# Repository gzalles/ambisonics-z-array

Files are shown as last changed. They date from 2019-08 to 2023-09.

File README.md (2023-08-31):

# MEMS Z-Array Mics

## [WIKI](https://github.com/gzalles/ambisonics-z-array/wiki)

A family of ambisonic microphones designed with MEMS capsules. These are affordable, easy-to-build arrays which can be used for multichannel audio recording (i.e., ambisonics).

Find an updated list of associated assets here:

1. m: Octave GNU code for plotting, analyzing and calibrating yourr own array
2. cad: various 3d objects you can print either online or at your university.
3. pcb: the files you need to make the pcbs or also you can have them made elsewhere.
4. svg: laser cutting files
5. conf: configuration files for kronlachner's convolution plug-in and filters
6. json: encoder presets for IEM MatrixMultiplier
7. wiki: instructions to build arrays

[AES Paper 1](https://www.researchgate.net/publication/320188555_A_Low-Cost_High-Quality_MEMS_Ambisonic_Microphone)

[AES Paper 2](https://www.researchgate.net/publication/338123588_Effects_of_Capsule_Coincidence_in_FOA_using_MEMS_Objective_Experiment)

<!-- TODO: move links to site.
 -->

## Pictures

<p align="center">
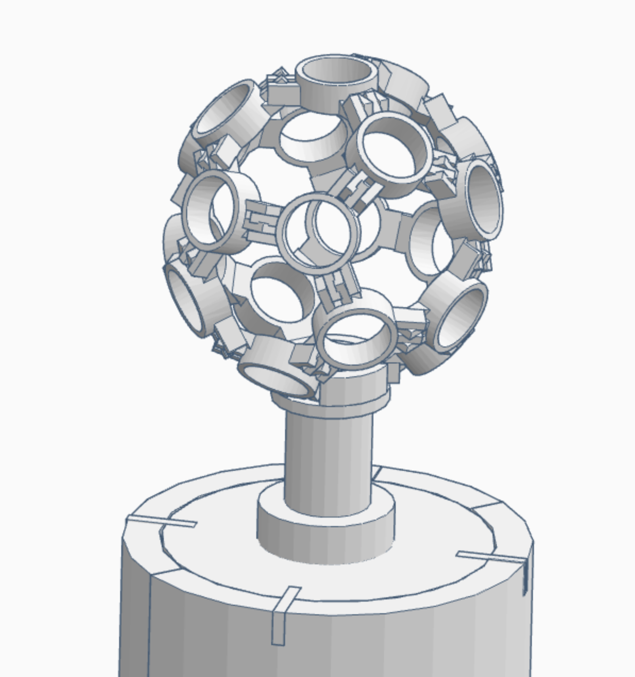
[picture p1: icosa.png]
  
  <figcaption>

BigSpHEAR by FLL (working on a permutation).

## Contributing

Feel free to fork and request merge if you are interested in the project. Email to gzalles at ucsd dot edu.

## Authors

* [**Gabriel Zalles Ballivian**](http://gabrielzalles.com/)

## License

This project is licensed under the MIT License - see the [LICENSE.md](LICENSE.md) file for details

## Acknowledgments

* Charles Middlicott
* Charlie Mydlarz
* Agnieszka Roginska
* Julian Vanesse
* Andrea Genovese
* Braxton Boren
* Fernando Lopez-Lezcano
* Julius O Smith
* Alex Tung (Qualcomm)
* Raimundi Gonzalez (MSMA)
* Spencer Capiello (NYU)

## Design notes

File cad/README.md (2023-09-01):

# CAD Files

Here are the STL files to build the various MC arrays. 

Key:
* MCH = name of the board
* ADA = adafruit 
* 16CH = 16 channel array
* 2D = two-dimensional (horizontal only)

* PDM = pulse density modulation (one of several protocols used)
* TDM = time domain multiplexing (same thing)
* I2S = Inter-IC Sound (same thing)
* IC = integrated circuit 

<!--
These are the CAD models we used for this design. At the moment these are not the best designs for low quality printers. We had to use a SLS printer (Form2) in order to get good results. We managed to get workable models on low-quality printers but after trial and error.

In the next design we are going to use the SpHear designs and modify them to make the MEMS fit. Hopefully that way these will be easier to print.

This file has 3 microphones since our experiment consisted of comparing these three designs.

The larger mic looks a little funny because the base is small relative to the head. This is because we wanted to keep the diameter of the cylinder the same and reduce print time. I was not sure my mic clip would work with larger diameter.

By the way, I use an alligator style mic clip [like this one](https://www.amazon.com/Audio-Universal-Microphone-Holder-Amc417x6/dp/B00P6VIPCS?ref_=fsclp_pl_dp_3) because the low quality prints can't handle the snap. Even if you use an SLS printer the neck is quite fragile so one of these bad boys would be good to have.

<p align="center">
  <img width="80%" height="80%" src="../img/threeSizes.JPG">
</p>
-->

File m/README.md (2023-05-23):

# Objective-C

I used ScanIR to get the impulse responses of my system. We also recycled the rotating mount project from our first paper to get polar measurements. This folder has functions and examples to calculate the DFR of the A-format signals and export the calibration filters.

I am eventually hoping to compare three methods of SMA encoding:

1. AF/BF calibration + static encoding matrix (using DFR for AF calibration and peak response for BF).
2. FM (filter matrix) encoding using ideal SHs to solve the system of linear equations.
3. Static encoding matrix plus radial filters. 

One could also combine these methods to try to find an optimal subjective solution. I am also conducting subjective evals via prolific.com

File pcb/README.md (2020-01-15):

# PCB Files

* 3_175mmRadius: panelized files (can also be found in zip format)
* mems_quart_board_ics_40720.brd : single PCB for editing if needed.

These are the panelized files for the ICS-40720 board that Charlie Mydlarz designed. The radius of the board is 3.175mm. These are the current boards we are using for the analog mems FOA mic. I also added the original without panelizing.

There is a lot of information of the datasheet online regarding these capsules. In order to acquire these board one must find a PCB manufacturer and pay them to send you the boards.

In our current design we opt for 1mm thickness.

We use 2-sided PCBs.

If you need the dimensions of the board you can use: http://www.gerber-viewer.com/

The only thing they ask is to upload the zipped file. I have added the zipped file for your convenience since all sites as for it this way.

You might also want to get a stencil. With it you can more easily apply the paste to you PCBs.

credit: charlie mydlarz.

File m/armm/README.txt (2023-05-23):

We should figure out how to build a robotic arm for IR measurements with low-cost printers and stuff. 

Fernando's arm is really expensive.

Part of this whole thing is automating the process as much as possible.

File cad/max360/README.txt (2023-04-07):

v1 max360 design (go pro camera attachment)

- use M3 screws, you need 2 per capsule (so 32) plus 2 more for the perf board and 2 more for the MCH board

- using the ICS41350 board by eighthree on github 

- mount should fit standard microphone mount 

- perf board is 22402A-18 

- MCHStreamer Kit board 

- top capsules are 20 degrees elevation.

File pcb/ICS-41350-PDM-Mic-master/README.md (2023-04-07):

# ICS-41350-PDM-Mic
Open Source pcb layout and design for InvenSense ICS-41350 PDM Mic

# Datasheet
https://www.invensense.com/wp-content/uploads/2016/02/DS-000047-ICS-41350-v1.1.pdf

# Order PCBs
https://oshpark.com/shared_projects/o22Ddhzi

# Order ICS-41350
https://www.digikey.ca/product-detail/en/tdk-invensense/ICS-41350/1428-1064-1-ND/6025660

You'll also need a 0805 10uF and a 0603 .1uF smd capacitors and a 0603 10K Resistor.

# Front and Back PCB Preview

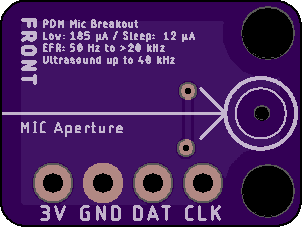
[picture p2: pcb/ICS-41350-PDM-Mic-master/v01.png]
Front PCB Design Front PCB, Aperture is highlighted by arrow

>The arrow points to where the hole for the mic goes.

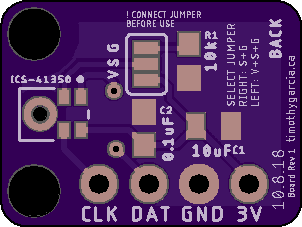
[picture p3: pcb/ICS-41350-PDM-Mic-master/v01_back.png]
Back PCB Design Back PCB, Jumper to select LEFT or RIGHT

>Bridge the S and G pad before using and bridge all three (S, G, V) if using module as RIGHT for stereo.

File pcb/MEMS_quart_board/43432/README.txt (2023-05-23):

43432 I2S Mic 

[VDD from J3 pin 2 on MCH]

LEFT and RIGHT PCBs (separate)

Left = CH1
Right = Ch2

Left tied to GRN (SEL)
Right tied to VDD (SEL)

MCH
///

BCLK > SCK 
LRCLK > WS 

Each data line has 2 channels. 
//////////////////////////////
J1 #2 input = channels 1/2
J1 #4 input = channels 3/4
etc.

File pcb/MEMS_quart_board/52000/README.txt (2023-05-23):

52000 TDM Mic

BCLK > SCK
FSYNC > WS

WS ---> WSO ---> WS ---> WSO 

Each data line has 8 channels. 
//////////////////////////////
J1 #2 input = channels 1-8
J1 #4 input = channels 9-16
etc.

[VDD from J3 pin 2 on MCH]

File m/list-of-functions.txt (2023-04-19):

working list of functions:
//////////////////////////

* load_spkr_resp - load speaker response (plot optional)
* load_AF - load A-format 
* load_single -load single capsule meas

* gen_refl_win - generate reflection window
* gen_spkr_eq - generate speaker EQ filter
* gen_helm_filt - generate helmholtz filter
* gen_AF_filt - generate A-format filters ("matching")
* gen_enc_mat - generate encoding matrix for array
* gen_BF_filt - generate B-format filters
* gen_reg_vec - generate regularization vector for N/K

* eq_AF - EQ A-format signals (for helm and/or A-format "matching" filter)
* eq_BF - EQ B-format signals

* export_AF_filt - export A-format filters in wav format
* export_BF_filt - export B-format filters in wav format
* export_enc_mat - export encoding matrix as csv

* plot_mag_one - plot a single IR (not polar) [magnitude]
* plot_mag_many - overlaying multiple IRs in a single figure [magnitude]
* plot_polar_single - plot polar for single capsule
* plot_polar_BF - plot polar B-format
* plot_polar_VM - plot polar virtual microphone 

! should we have plots for phase response?

* calc_dfr - calculate diffuse field response(s)
* calc_nk - calculate nelson/kirkeby (N/K) inverse filter
* calc_snr - calculate snr of signal 
* calc_toa - calculate time of arrival differences for all capsules. 

* norm_AF - normalize the AF signals based on global maxima
* norm_BF - normalize the BF signals based on W (loudest harmonic)

* conv_sweep2ir - convert sweep to ir
* conv_AF2BF_FOA - use a simple sum and difference matrix to convert AF to BF (FOA only).

ideas:
/////

1. should we make a function that precedes the DFR filter generation that adjusts the gain of the AF signals based on fulcrum offset? [gain_match_AF] this might be easy for FOA and octo but how about 16 channnel mic? is this the same as the AF filter using DFR? maybe it is... 

calc_toa:

We can use these to time-align the IRs. In other words, we can phase match the capsules. Important when array is not perfectly centered in ARMM. I think the way to do this is average all the FREQUENCY RESPONSES (not mag), then get the average phase response, then get the group delay, then match (Q-1) capsules. 

Another method might be to use the time domain iFFT averaged frequency response, and use some threshold to determine where the sweep starts. 

* mostly applicable to measurements, not so useful in real life. the capsules and CAD models are quite precise. 

* calculate SNR (create function)

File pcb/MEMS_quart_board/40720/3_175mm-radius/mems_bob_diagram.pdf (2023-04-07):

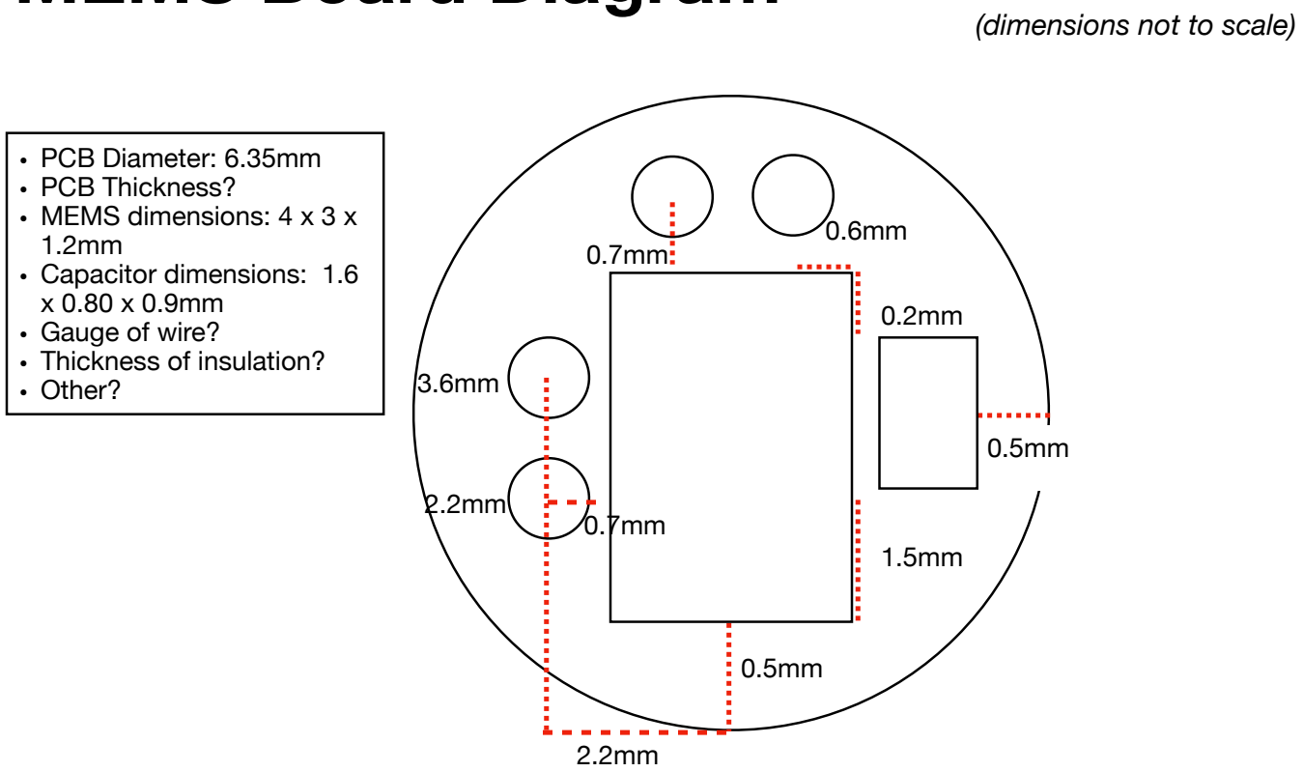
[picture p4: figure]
(dimensions not to scale); • PCB Diameter: 6.35mm • PCB Thickness? • MEMS dimensions: 4 x 3 x 1.2mm • Capacitor dimensions: 1.6 x 0.80 x 0.9mm • Gauge of wire? • Thickness of insulation? • Other?

http://www.gerber-viewer.com/ used gerber-viewer to measure (it takes a zipped file)

1.65mm between the two holes on top
1.4mm between the two holes on the side

# MEMS Board Diagram

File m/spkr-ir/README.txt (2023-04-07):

In order to confirm that REW does use the calib file you should compare the responses of both wav files!

/

Initial test of u-mik at home. I think I will try to do this again but do 4 or 8 repetitions. I have to put the dog in my room, he was moving around. 

The calib file incorporated the calibration file. I believe the export takes into account the calib file so long as it is correctly loaded, although I am not sure. I am still new to REW.

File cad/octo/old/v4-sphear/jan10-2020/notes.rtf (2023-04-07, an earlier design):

I used 50 percent infill on this print
I used the highest detail possible 0.18mm resolution.

I used MILANO at Envision and the PETG material (IC3D)
I did not use the glue stick.

The weird thing is the resolution setting for some of the other printers for high is 0.14mm. Maybe it has to do with the material?

——

I switched to the millennium falcon. It has PLA and .14mm resolution. The print looked like it was kind of failing on the other printer. It is not looking very good on this one but we’ll see. I will let is finish.

I also printed a few extra ones just in case some of them did not work.

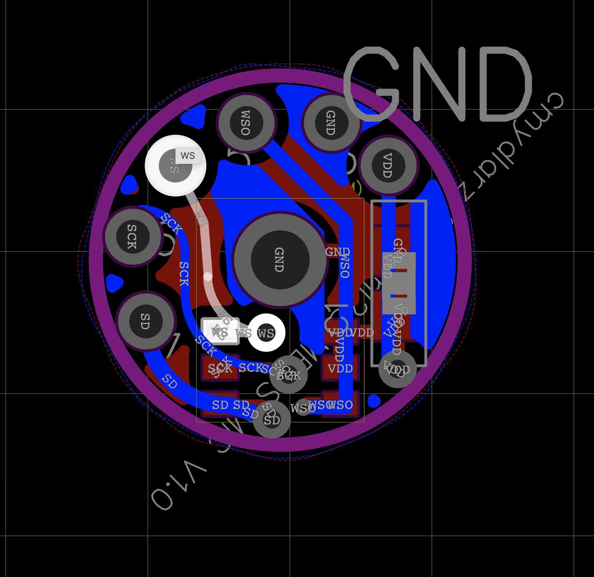
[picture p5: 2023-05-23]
pcb/MEMS_quart_board/52000/52000-pcb-pinout.png

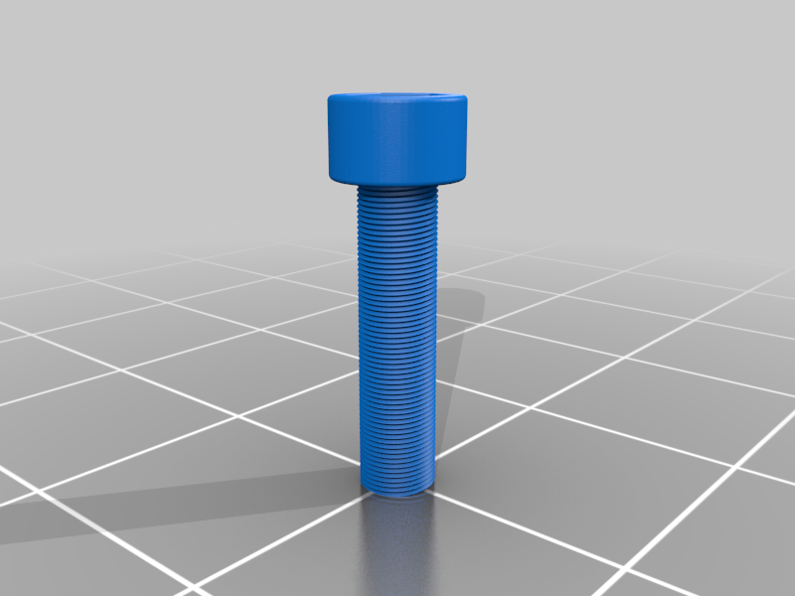
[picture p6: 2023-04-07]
cad/dl/screws/M3_SCREW_WITH_NUT_3730355/images/M3_HEX_SCREW.png

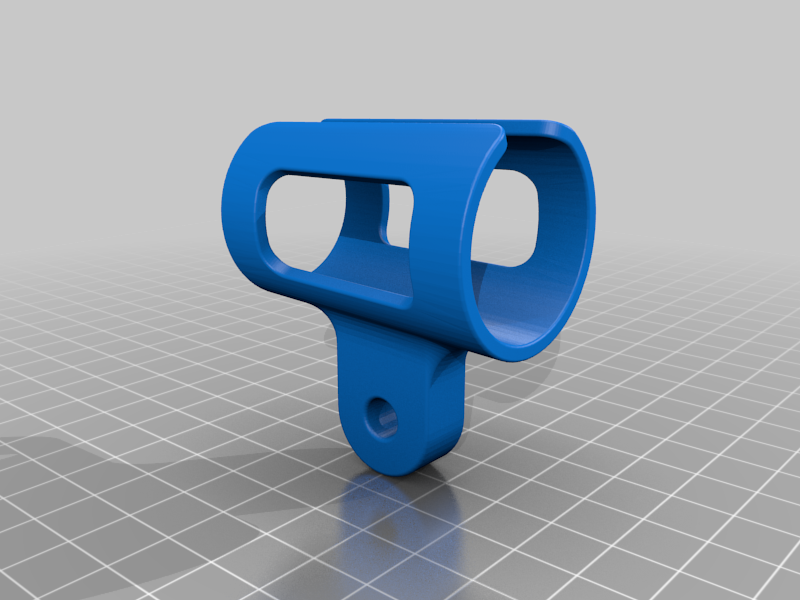
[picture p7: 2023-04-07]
cad/dl/mic-holder/images/Mic_Holder_Standard_Size.png

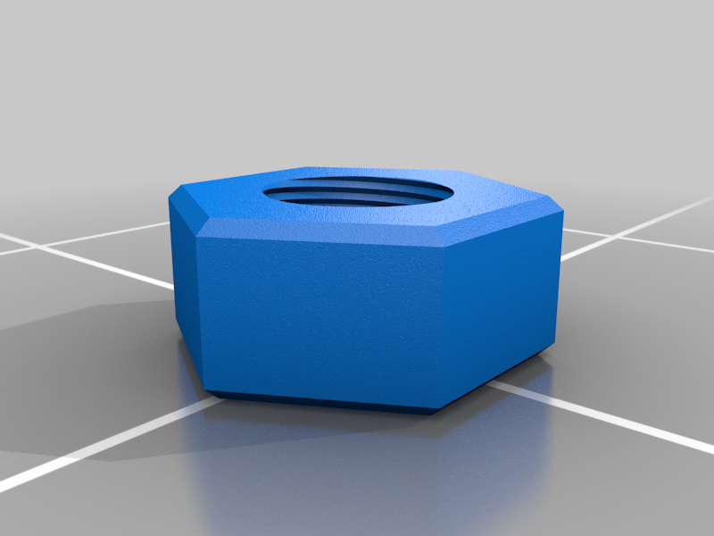
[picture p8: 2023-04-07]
cad/dl/screws/M3_SCREW_WITH_NUT_3730355/images/M3_HEX_NUT.png

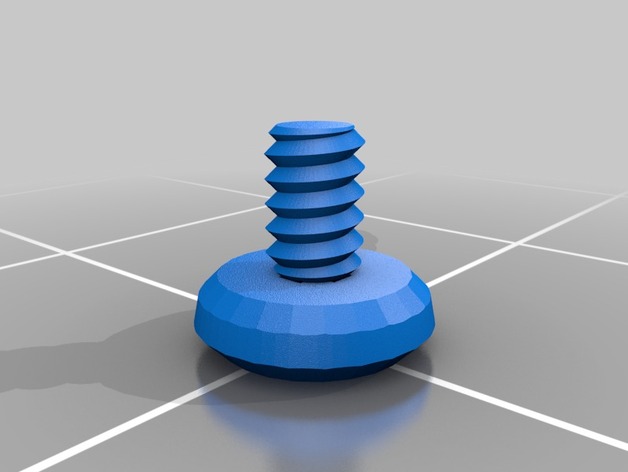
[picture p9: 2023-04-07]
cad/dl/screws/M2_Screw_Attempt__3_for_T732_912171/images/nut_job_20150705-13585-1r5dxre-0.jpg

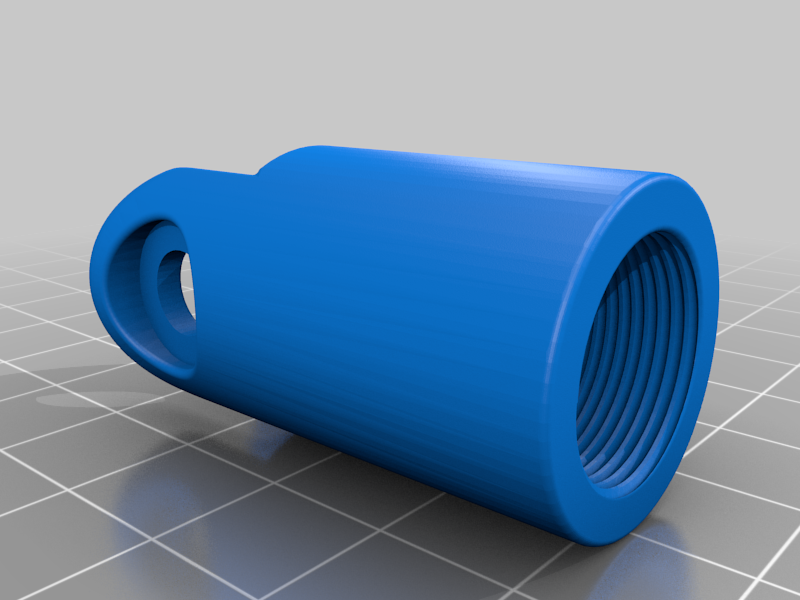
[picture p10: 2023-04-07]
cad/dl/mic-holder/images/Stand_Mount.png

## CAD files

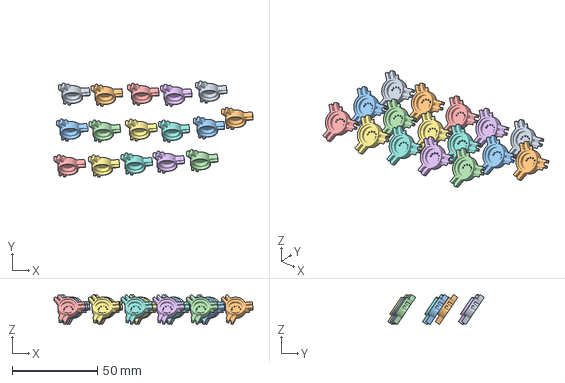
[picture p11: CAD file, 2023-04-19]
cad/bigSpHEAR_mems/big-3d-printed/gcode/SLS/main-cap-holder-new.3mf
116.8 x 56.7 x 17.6 mm
main-cap-holder-new.stl x 16

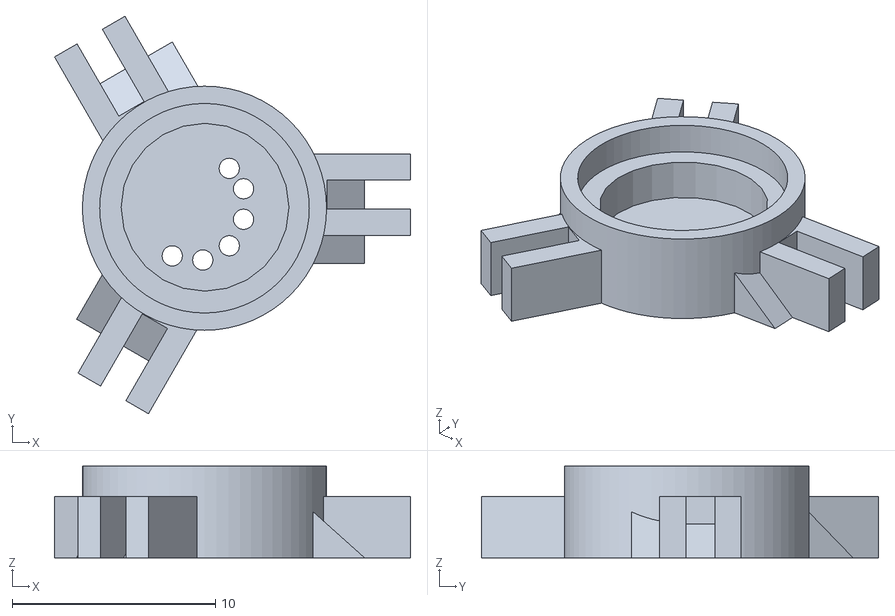
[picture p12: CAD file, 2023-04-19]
cad/bigSpHEAR_mems/big-3d-printed/main-cap-holder-new.stl
17.5 x 19.5 x 4.50

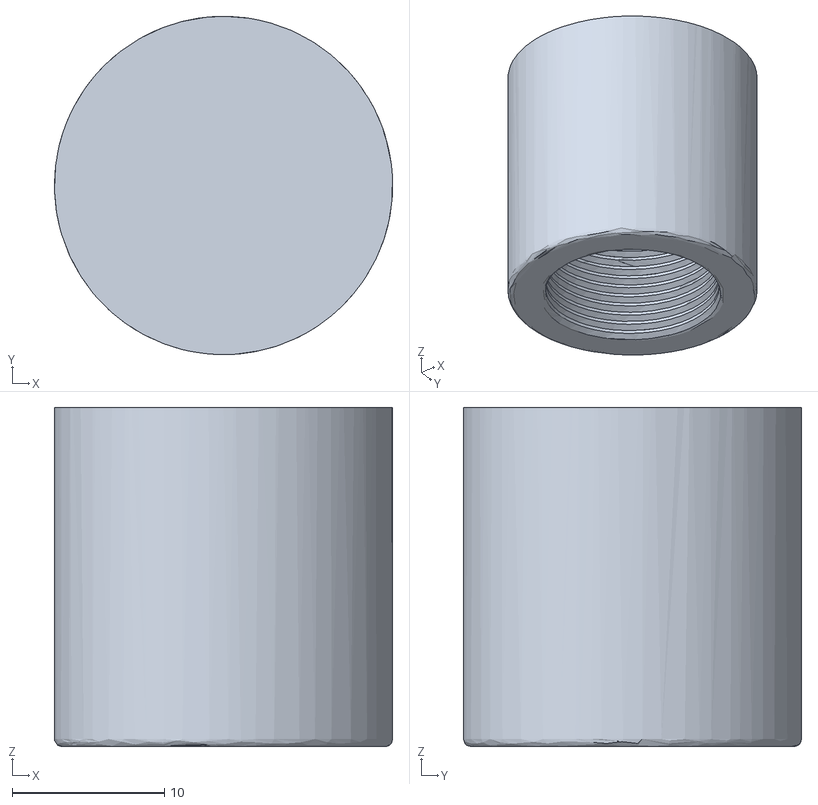
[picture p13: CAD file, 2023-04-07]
cad/_temp/missing/1/mic-holder-tube.stl
22.2 x 22.2 x 22.3

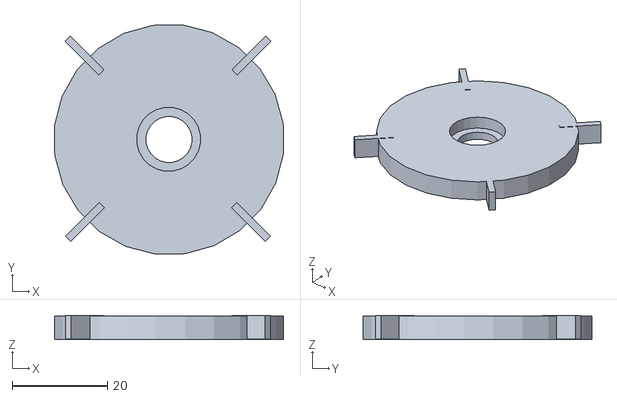
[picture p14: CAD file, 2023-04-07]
cad/_temp/missing/2/top 2.stl
48.1 x 48.1 x 5.09

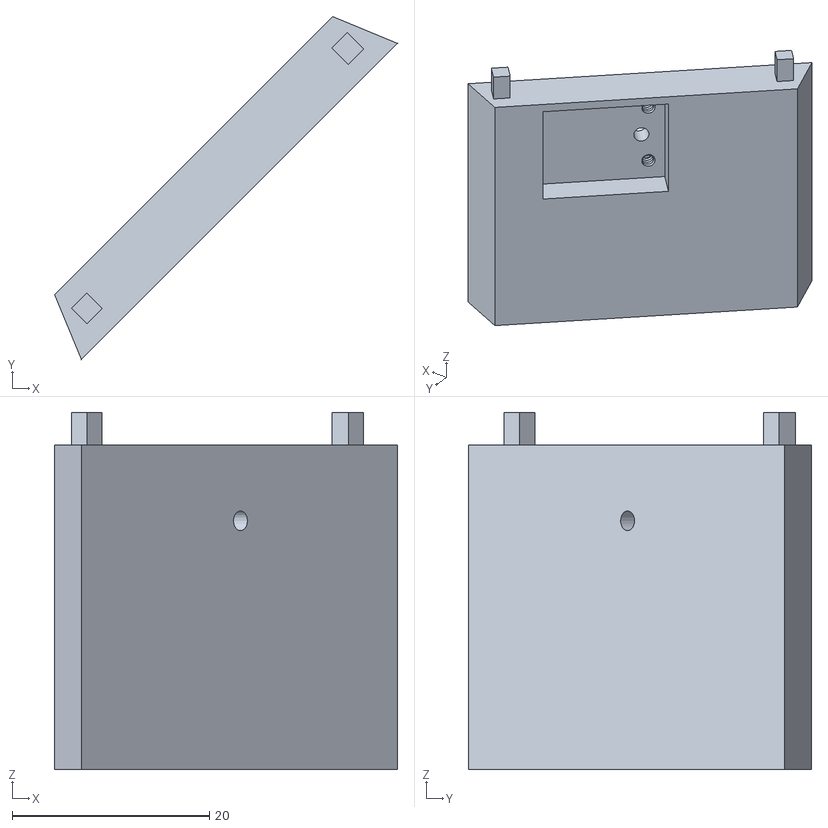
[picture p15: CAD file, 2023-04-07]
cad/_temp/missing/4/sideA.stl
34.8 x 34.8 x 36.2

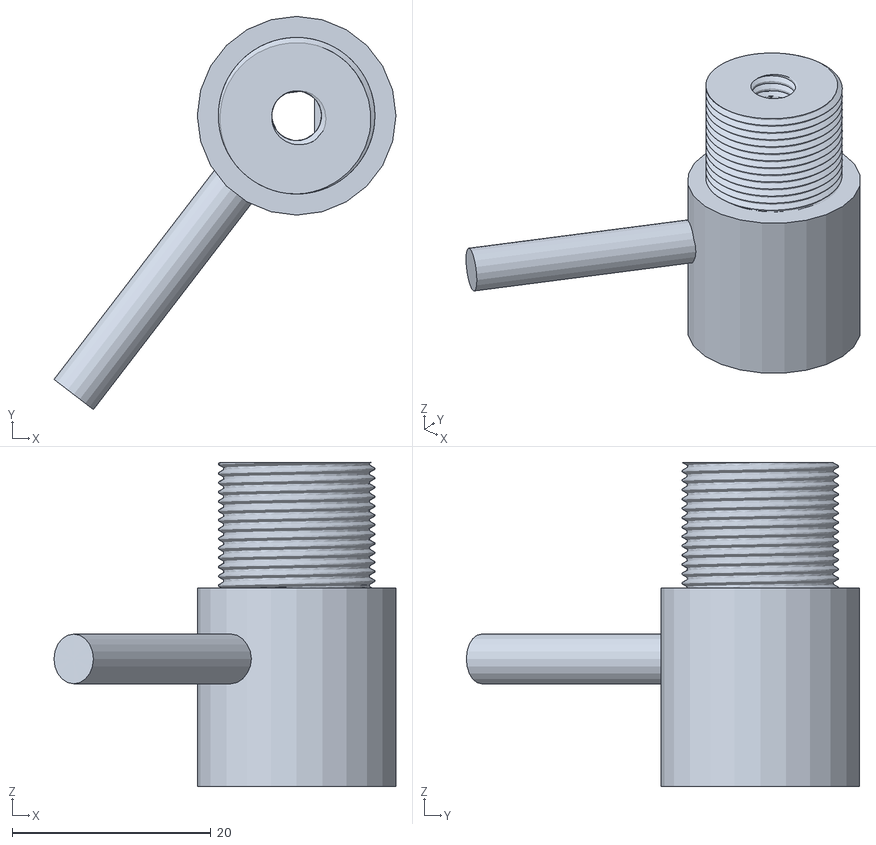
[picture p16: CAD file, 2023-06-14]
cad/armm/armm-attachment_V2.stl
34.4 x 39.6 x 32.6

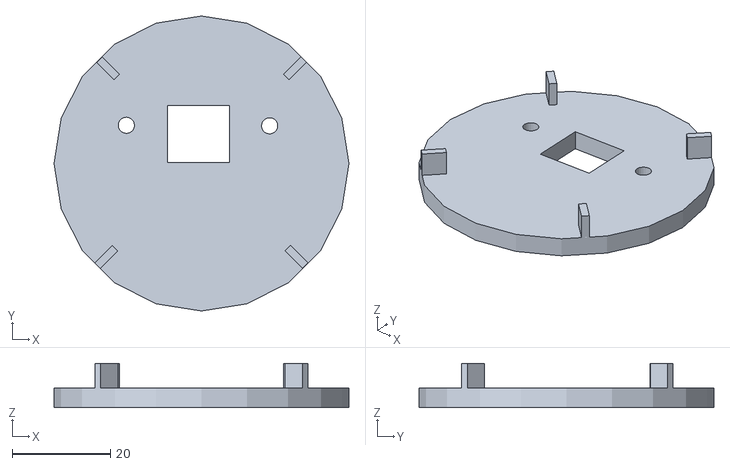
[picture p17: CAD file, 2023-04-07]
cad/bigSpHEAR_mems/big-3d-printed/cpy/bottom.stl
60.0 x 60.0 x 9.00

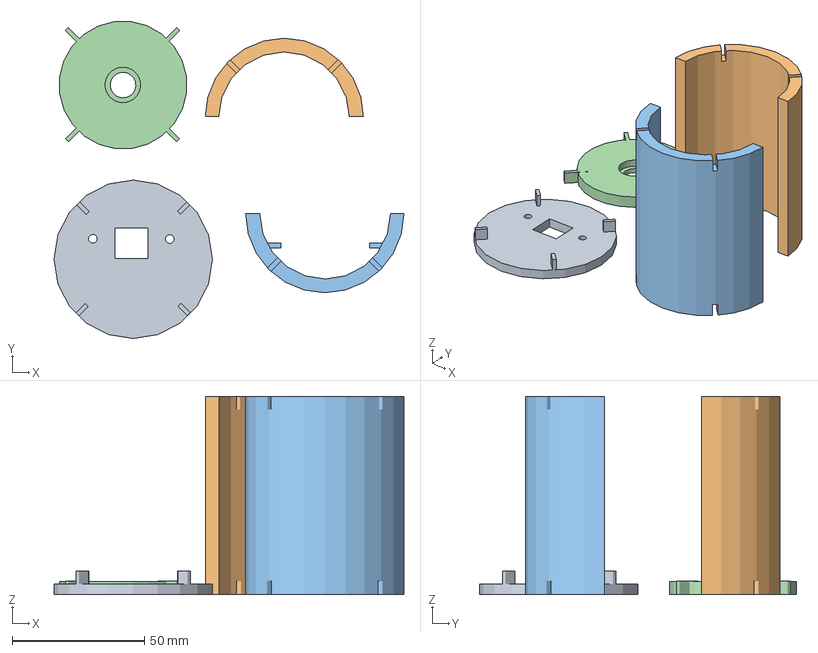
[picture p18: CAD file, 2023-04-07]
cad/bigSpHEAR_mems/big-3d-printed/gcode/body.3mf
132.6 x 120.1 x 75.1 mm
bottom.stl
side-a.stl
side-b.stl
top.stl

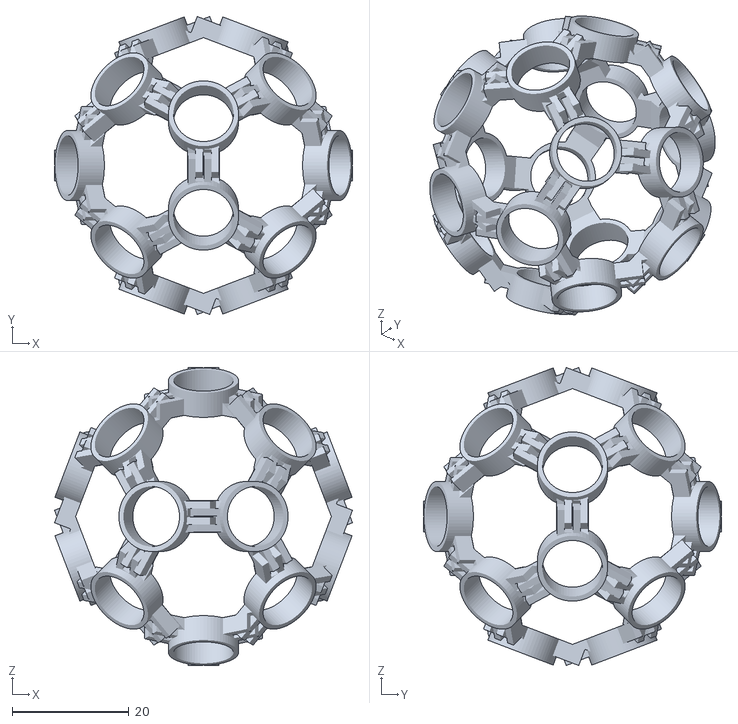
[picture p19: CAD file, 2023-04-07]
cad/bigSpHEAR_mems/BigSpHEAR_20.stl
51.1 x 51.1 x 51.1

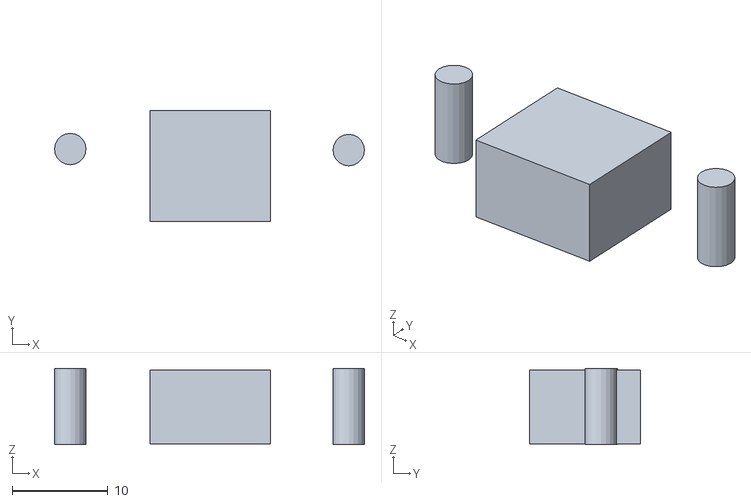
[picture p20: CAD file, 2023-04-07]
cad/bigSpHEAR_mems/helper/mch-hole.stl
32.4 x 11.6 x 8.00

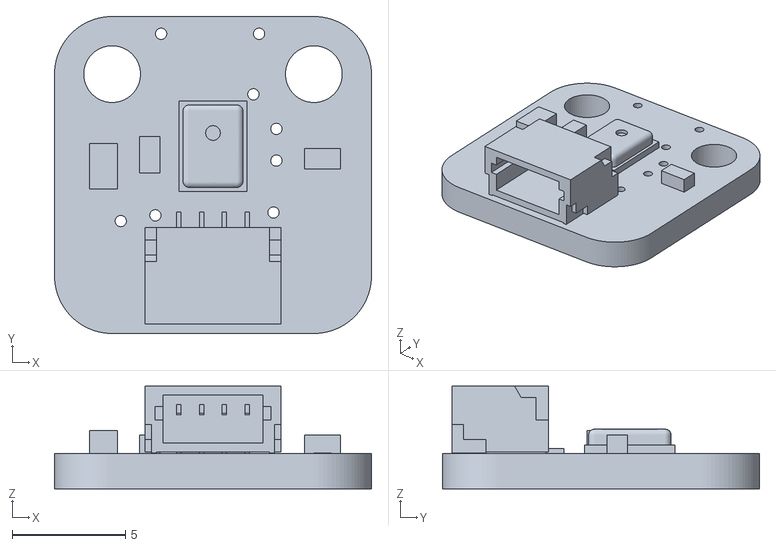
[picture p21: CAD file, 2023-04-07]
cad/dl/ada/PDM Mic with JST SH.stl
14.0 x 14.0 x 4.53

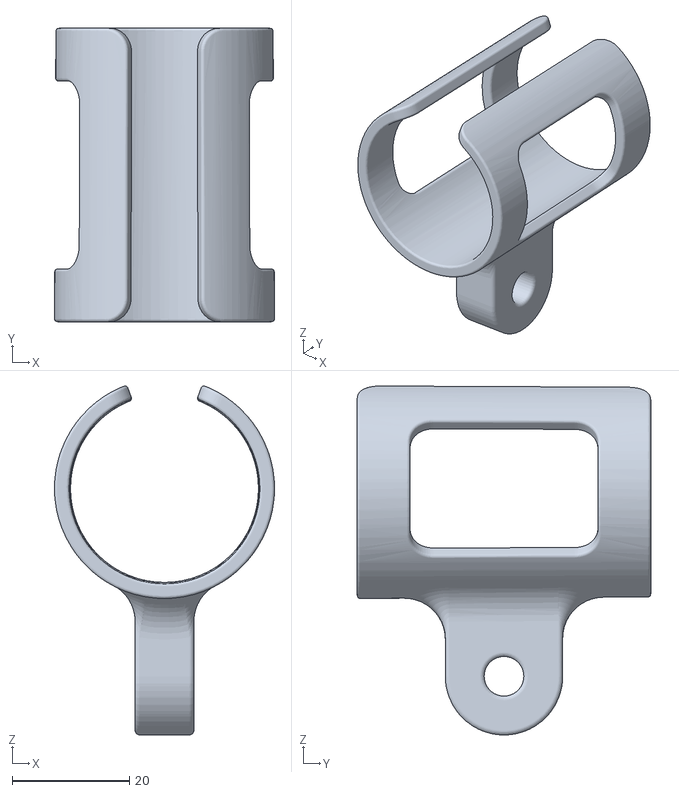
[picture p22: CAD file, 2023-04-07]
cad/dl/mic-holder/files/Mic_Holder_Samson_Q2U.STL
37.5 x 50.0 x 59.5

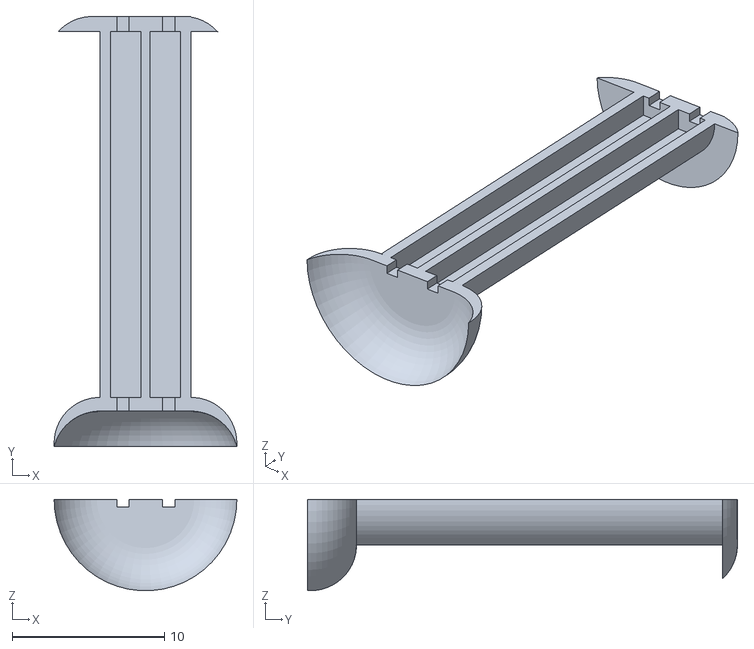
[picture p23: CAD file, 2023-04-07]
cad/dl/msma/Link.stl
12.0 x 28.2 x 5.99

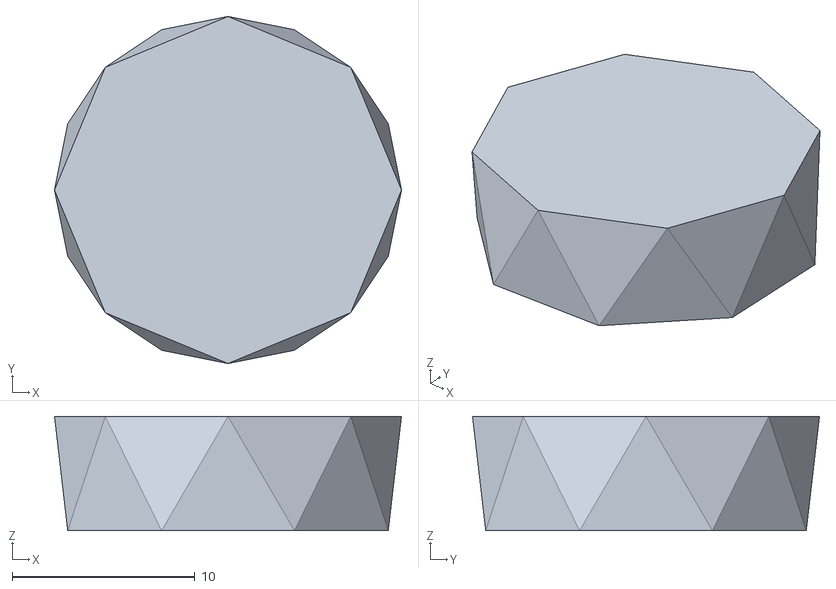
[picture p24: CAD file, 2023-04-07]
cad/dl/octagonal_antiprism.stl
19.0 x 19.0 x 6.25

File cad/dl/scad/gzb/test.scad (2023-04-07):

// GZB

// we want to make 4 circles of a desired radius 
// translate and rotate them a desired amount 

// determine the radius of our initial circle
radius = 6.5; 
//get the dihedral angle for FOA
rotate([54.7356, 0, 0]) circle(radius);

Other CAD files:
cad/bigSpHEAR_mems/big-3d-printed/main-cap-holder.stl
cad/dl/scad/gzb/tetrahedron.stl
cad/gzb.stl
cad/_temp/missing/2/neck.stl
cad/_temp/missing/3/side-a.stl
cad/_temp/missing/3/side-b.stl
cad/_temp/missing/4/sideB.stl
cad/_temp/missing/4/top.stl
cad/armm/armm-attachment.stl
cad/bigSpHEAR_mems/BigSpHEAR_20_single.stl
cad/bigSpHEAR_mems/BigSpHEAR_20_single_noRamp.stl
cad/bigSpHEAR_mems/big-3d-printed/cpy/side-a.stl
cad/bigSpHEAR_mems/big-3d-printed/cpy/side-b.stl
cad/bigSpHEAR_mems/big-3d-printed/empty-cap-holder.stl
cad/bigSpHEAR_mems/big-3d-printed/filled-cap-holder.stl
cad/bigSpHEAR_mems/big-3d-printed/gcode/SLS/big-3d-printed-SLS.3mf
cad/bigSpHEAR_mems/big-3d-printed/gcode/big-3d-printed.3mf
cad/bigSpHEAR_mems/big-3d-printed/lid.stl
cad/bigSpHEAR_mems/big-3d-printed/neck.stl
cad/dl/icosa.stl
cad/dl/mic-holder/files/Mic_Holder_Standard_Size.STL
cad/dl/mic-holder/files/Stand_Mount.STL
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

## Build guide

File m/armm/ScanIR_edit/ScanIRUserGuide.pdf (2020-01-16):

ScanIR

USER’S

GUIDE

# Introduction

ScanIR

is

an

application

for

high-‐fidelity

impulse

response

measurement,

storage,
and

analysis

via

Matlab.

ScanIR

is

currently

available

on

Mac

OSX

platforms

only.

To
use

ScanIR,

you

will

need

the

Psychtoolbox-‐3

toolkit

for

Matlab,

which

allows
simultaneous

multichannel

audio

I/0,

which

is

necessary

for

recording

impulse
responses.

## Getting

## Started

To

use

the

application,

just

navigate

to

the

ScanIR

folder

in

your

Matlab

directory,
type

‘ScanIR’

into

the

prompt

window,

and

hit

enter.

You

will

see

a

welcome

screen
(Fig.

1)

offering

two

options:

create

a

new

session,

or

load

a

previous

session.

For
now,

just

click

“Create

New

Session.”

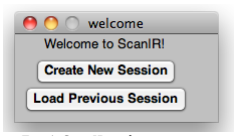
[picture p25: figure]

Fig.

1.

ScanIR

welcome

screen

You

are

now

at

the

initialization

screen

for

a

new

measurement

session

(Fig.

2).

This
window

contains

options

for

initializing

the

static

parameters

of

your

measurement
session

(those

that

will

not

change

over

the

course

of

a

session).

Fig.

2.

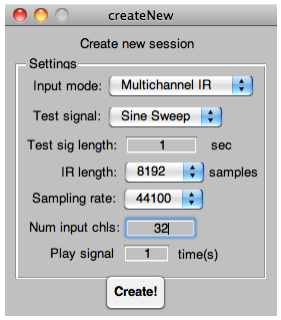
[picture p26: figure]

Initialization

screen

for

new

ScanIR

measurement

session

The

first

menu

on

the

initialization

screen

asks

you

to

select

an

Input

Mode.

ScanIR
has

three

primary

uses,

which

are

each

implemented

in

separate

input

modes:

1) Mono

IR –

records

a

single-‐channel

room

impulse

response.
2) HRIR –

records

a

series

of

two-‐channel

head-‐related

impulse

responses

for
given

azimuth

angle,

elevation

angle,

and

distance.

This

mode

additionally
may

record

a

single

position

at

once,

or

it

may

be

configured

for

recording

an
array

of

positions

in

sequence.

Because

HRIR

measurement

sessions

often
involve

a

large

number

of

regularly

defined

positions,

HRIR

mode

is

designed
to

allow

a

quick

definition

of

an

array

of

measurements

to

expedite

the
process.

While

the

other

input

modes

only

allow

output

from

a

single

channel
at

a

time,

HRIR

mode

also

allows

the

possibility

of

measuring

impulse
responses

from

consecutive

loudspeakers

in

quick

succession,

allowing

even
faster

HRIR

measurements.

If

you

select

‘HRIR’

as

your

input

mode,

another
menu

will

appear

at

the

bottom

of

the

initialization

screen

that

reads

Output
Mode.

This

menu

allows

you

to

select

whether

you

want

to

measure

one
HRIR

position

at

a

time

(1

channel

output)

or

multiple

channels
consecutively,

up

to

the

limit

of

your

audio

interface

(multichannel

output).
3) Multichannel

IR –

records

a

series

of

impulse

responses

on

a

dense
microphone

array

to

measure

sound

propagation

in

space

across

different
frequencies.

If

you

select

‘Multichannel

IR’

as

your

input

mode,

a

text

box

will
appear

at

the

bottom

of

the

initialization

screen

that

reads

Num

input

chls.
This

allows

you

to

set

the

number

of

channels

that

you

will

be
simultaneously

recording

impulse

responses

with,

up

to

the

limit

of

your
audio

interface.

The

next

menu

asks

you

to

select

the

Test

Signal.

This

refers

to

the

type

of
excitation

signal

that

will

be

played

and

recorded

to

measure

impulse

responses.
The

options

are

Sine

Sweep,

which

plays

a

logarithmic

swept

sinusoid

from

20

Hz

to
20

kHz;

MLS

(Maximum

Length

Sequence),

which

plays

a

noise-‐like

burst

of

sound
calculated

to

have

equal

energy

at

all

frequencies;

and

Golay

Codes,

a

pair

of

noise-‐
like

sounds

whose

autocorrelation

functions

sum

to

an

idealized

impulse

response.
Sine

Sweep

is

generally

better

for

quiet

environments,

as

it

bypasses

natural
nonlinearities

in

the

audio

output

system

being

used.

MLS

and

Golay

Codes

are

more
robust

to

background

noise.

The

third

option

on

the

initialization

screen

asks

you

to

set

the

value

of

the

Length
of

the

Test

Signal

being

used.

This

must

be

greater

than

zero,

with

a

maximum
value

of

10

seconds.

The

next

popup

menu

asks

you

to

set

the

Length

of

the

Impulse

Responses

you
will

be

recording.

If

you

are

in

mono

input

mode,

this

will

give

values

from

1-‐9
seconds,

as

acoustic

room

impulse

responses

can

be

very

long

in

reverberant
environments.

If

you

are

in

HRIR

mode,

this

will

give

values

in

increasing

powers

of
2

samples,

from

128

to

8192.

This

is

because

the

lengths

of

impulse

responses

corresponding

to

the

filtering

effects

of

your

head

are

very

short.

In

fact,

any

content
from

room

reflections

should

be

windowed

out

of

the

signal

to

preserve

only

the
HRIR

itself.

If

you

are

in

multichannel

mode,

you

will

have

an

additional

option

of
choosing

samples

or

seconds

as

your

time

unit,

depending

on

the

context

of

your
impulse

response

measurement

session.

Next,

the

initialization

screen

will

ask

you

to

set

your

Sampling

Rate.

This

defaults
to

44100

Hz,

but

can

be

changed

to

values

from

22050

Hz

to

96000

Hz.

Make

sure
that

the

sampling

rate

you

choose

is

compatible

to

your

audio

interface.

The

final setting

(other

than

mode-‐specific

options)

allows

you

to

change

the
Number

of

Times

the

Test

Signal

is

Played.

This

defaults

to

1,

but

may

be
increased

to

as

many

as

5

times.

If

this

is

set

to

a

number

greater

than

1,

ScanIR

will
play

and

record

multiple

test

signals

and

average

their

response,

allowing

irregular
background

noise

to

be

eliminated

from

the

final

impulse

response.

After

you’ve

finished

initializing

your

session,

hit

Create!

and

ScanIR

will

create
your

session,

with

the

specifications

you’ve

chosen.

ScanIR

will

now

open

up

its
main

window

for

recording

and

analyzing

impulse

responses.

# Using

# ScanIR

The

following

instructions

will

help

you

get

familiar

with

the

specific

uses

of

the
different

input

modes

in

ScanIR.

## Mono

## Input

## Mode

Mono

input

is

the

simplest

of

the

three

input

modes.

ScanIR

uses

this

mode

to
record

single

impulse

responses,

one

at

a

time

(fig.

3).

This

is

most

appropriate

for
recording

room

impulse

responses,

which

characterize

the

early-‐

and

late-‐field
reverberation

in

an

acoustic

space.

A

future

version

of

ScanIR

will

include

additional
analysis

tools

for

calculating

room

acoustic

parameters

from

these

impulse
responses.

If

you

look

in

the

upper-‐left

of

the

main

window

you

will

see

the

Settings

panel.
This

includes

most

of

the

static

data

you

set

in

the

initialization

screen.

In

addition,
the

Output

chl

box

allows

you

to

edit

the

current

output

channel

that

ScanIR

will

use
for

its

test

signal.

The

number

of

the

output

channel

corresponds

to

the

signal
routing

used

by

your

audio

interface.

Beneath

this,

you

will

see

the

Description

panel.

This

contains

the

specific

position
data

and

other

information

about

a

single

impulse

response

measurement.

Though
azimuth

and

elevation

are

used

less

when

describing

room

impulse

responses,

they
can

be

set

here

if

the

source’s

position

relative

to

the

receiver

is

important

to

the
measurements.

The

third

parameter,

distance,

may

be

more

useful

but

is

optional

as
well.

The

comments

field

allows

unrestricted

string

input

for

any

information

that
you

wish

to

record

about

a

particular

position.

For

instance,

this

would

allow

you

to
instead

record

x-‐y-‐z

coordinates

for

source

positions

rather

than

defining

the

source
relative

to

the

receiver.

*

PLEASE

NOTE

*

The

data

about

a

position

is

stored

when

that

position

is
measured!

Therefore

you

must

enter

all

this

data

before

hitting

the

Measure

button.

In

the

lower-‐left

corner,

you

will

see

the

Control

Panel.

This

allows

you

to

measure
new

impulse

responses

and

to

index

through

previously

measured

responses.

The
Measure

button

sends

the

selected

test

signal

through

your

audio

system

on

the
channel

selected

in

the

Settings

panel.

Your

system

will

simultaneously

record

this
signal

and

deconvolve

to

generate

an

impulse

response

for

that

source-‐receiver
combination.

If

you

click

the

checkbox

labeled

Save

backup

WAV,

your

system

will
save

a

wave

file

of

the

raw

recorded

data

into

the

ScanIR

directory.

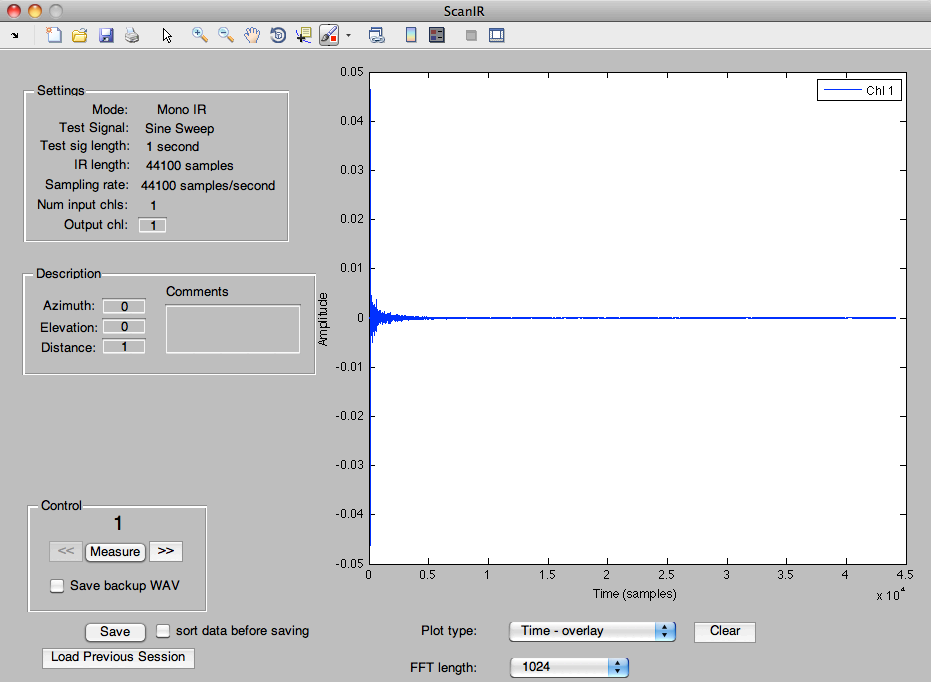
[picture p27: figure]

Fig.

3.

Main

application

screen,

Mono

IR

mode
On

the

right-‐hand

side

of

the

main

screen,

you

will

see

the

Data

Plot.

This

is

where
the

impulse

responses

will

be

viewed

in

either

the

time

or

frequency

domains.

The
x-‐axis

will

either

represent

time

(in

samples)

or

frequency

(in

hertz),

depending

on
the

visualization

domain.

The

type

of

visualization

is

selected

in

the

Plot

Type

menu
below.

In

Mono

mode,

only

two

visualization

options

are

available:

Time

–

overlay
and

Frequency

–

overlay.

Below

this

menu

is

the

FFT

Length

menu,

which

allows
you

to

change

the

length

of

FFT

used

to

visualize

the

frequency

domain.

A

larger

FFT
size

will

give

you

higher

frequency

resolution.

Finally,

the

Data

Plot

may

be

cleared
at

any

time

using

the

Clear

button,

although

your

recorded

data

will

remain

and
may

be

plotted

again

by

clicking

on

the

appropriate

domain

in

the

Plot

Type

menu.

In

addtion

to

the

visualization

menu,

the

normal

Matlab

plot

visualization

tools

are
available

at

the

top

of

the

screen

for

zooming/dragging

the

image,

as

well

as
rotating

(for

3D

plots,

available

in

ScanIR’s

multichannel

modes).

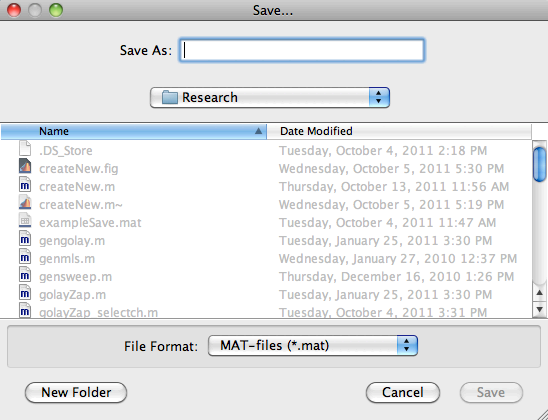
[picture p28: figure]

Fig.

4.

Save

file

dialog

Below

the

Control

panel,

you

will

see

the

Save

and

Load

Previous

Session

buttons.
The

save

button

allows

you

to

save

all

recorded

measurements

in

the

session,

along
with

all

the

position

data

associated

with

them,

as

a

.mat

file

(fig.

4).

If

you

select

the
checkbox

labeled

sort

data

before

saving,

the

impulse

responses

will

not

be

stored
in

the

order

they

were

measured

–

rather

they

will

be

indexed

first

by

the

‘azimuth’
value

stored

to

each

one,

and

secondarily

by

the

‘elevation’

value.

Thus,

a

sorted

set
of

impulse

responses

will

contain

all

measurements

at

the

lowest

given

azimuth,
from

lowest

to

highest

elevation,

followed

by

all

measurements

at

the

second

lowest
azimuth,

etc.

This

sorting

is

most

useful

in

HRIR

multichannel

output

mode,

but

it

is
still

available

in

Mono

mode

in

case

data

positions

might

need

to

be

re-‐sorted.
Finally,

the

Load

button

allows

you

to

load

a

previously

saved

dataset

of

impulse
response

measurements.

This

is

identical

to

the

Load

button

available

when

you
first

run

ScanIR.

When

you

load

new

measurements,

your

current

data

(if

any)

will
be

lost,

so

be

sure

to

save

before

loading.

However,

if

you

need

to

quickly

sort

the
data

you’re

using,

you

can

save

(with

the

sort

option

checked),

and

then

load

the
.mat

file

you

just

saved

to

view

your

data

in

a

new

order.

## HRIR

## Input

## Mode

Head-‐Related

Impulse

Responses

(HRIRs)

refer

to

the

set

of

binaural

filtering

effects
produced

by

the

torso,

head,

and

outer

ears.

Because

these

filters

change

based

on
position,

recording

them

often

requires

a

dense

array

of

measurements

that

are
regularly

spaced.

For

this

reason,

ScanIR

has

a

specific

mode

dealing

with

the
measurement

of

HRIRs.

In

addition,

HRIR

input

mode

has

the

option

of

1-‐channel
output

(the

same

as

in

Mono

input

mode)

or

multichannel

output.

We

will

examine
1-‐channel

output

first.

1-channel

output
Most

of

the

main

window

will

look

the

same

in

HRIR

mode

as

in

Mono

mode.
However,

you

may

notice

that

the

Azimuth

and

Elevation

fields

in

the

Description
panel

are

now

grayed

out.

This

is

because Azimuth

and

Elevation

are

controlled
through

the

HRIR

Locations

panel,

located

below

(fig.

5).

This

allows

the

user

to
define

arrays

of

regularly

spaced

source

positions,

which

will

automatically

update
when

the

application

progresses

to

the

next

measurement.

This

panel

works

by
defining

a

start

angle,

interval

angle,

and

end

angle

for

both

azimuth

and

elevation.
The

interval

may

be

defined

in

a

positive

or

negative

direction.

In

addition,

once

you
are

done

with

the

currently

defined

array

of

measurements,

you

may

update

the
panel

to

generate

a

new

array

of

positions

if

you

need

different

measurement
densities

for

different

areas.

Once

the

current

array

is

defined,

the

Azimuth

and
Elevation

fields

will

update

automatically,

again

cycling

through

the

azimuths

and
elevations

defined

by

the

panel.

*

PLEASE

NOTE*

that

you

will

still

need

to

update

the

Output

Chl

field

for

each

new
measurement,

according

to

the

channel

you

need

for

the

defined

position!

Fig.

5.

HRIR

Locations

Panel
HRIR

mode

also

contains

extra

visualization

options:

in

addition

to

the

default
‘overlay’

options

for

the

time

and

frequency

domain,

HRIRs

may

also

be

viewed

as
Time

–

cascade

or

Frequency

–

cascade.

These

options

put

the

separate

channels

on
different

axes,

one

on

top

of

the

other,

rather

than

plotting

them

with

different
colors

on

the

same

axis.

In

addition,

a

fifth

option

is

available,

Frequency

–

cascade
chl.

This

cascade-‐by-‐channel

option

is

only

available

if

you

have

recorded

multiple
positions.

When

this

is

the

case,

this

option

allows

you

to

view

the

intensity

by
frequency

for

a

single

channel

across

multiple

measurements.

3D

plot

rotations

are
useful

for

viewing

this

3-‐dimensional

data

plot.

Multichannel

output
Since

HRIR

measurement

sessions

often

require

a

large

amount

of

measurements,

it
can

often

expedite

the

process

to

automate

measurements

by

using

a

multichannel
system

and

measuring

consecutive

channels

in

immediate

succession.

ScanIR’s
multichannel

output

mode

is

designed

for

this,

and

only

works

when

in

HRIR

input
mode.

When

you

select

HRIR

as

the

input

mode

in

the

ScanIR

Initialization

screen,

you

will
see

that

another

menu

appears

allowing

you

to

choose

1-channel

output

or
multichannel

output.

If

you

select

multichannel,

another

field

will

appear

asking

you
to

input

the

number

of

channels

you

wish

to

output

to,

up

to

the

limit

of

your

audio
interface.

Once

this

is

instantiated,

ScanIR

will

take

consecutive

measurements

from
channel

1

up

to

the

maximum

channel

number

you

selected.

In

the

main

screen’s

Settings

panel,

you

will

see

that

the

Output

chl

field

is

now
grayed

out

and

contains

a

series

of

numbers

(1-‐8,

for

instance).

In

addition,

the

end
angle

fields

are

grayed

out

for

both

Azimuth

and

Elevation

in

the

HRIR

Locations
panel.

This

is

because

each

time

you

hit

measure,

you

will

cycle

through

a

complete
array

of

positions,

and

the

size

of

the

array

will

equal

the

number

of

output

channels
you

selected

for

this

measurement

session.

If

you

are

arranging

your

loudspeakers
on

a

diagonal,

as

is

common

during

HRIR

measurements,

you

should

define

the
interval

angle

field

to

be

nonzero

for

both

Azimuth

and

Elevation.

Whereas

in

single-‐
channel

output

mode

this

array

defined

a

rectangular

array

of

size

(number

of
azimuth

positions

by

number

of

elevation

positions),

the

multichannel

version

will
now

only

define

those

positions

on

the

diagonal.

For

instance,

if

you

chose

4-‐channel

output,

and

defined

your

azimuths

as

starting

at
0

degrees

with

an

interval

of

10

degrees,

while

your

elevations

began

at

-‐10

degrees
with

an

interval

of

5

degrees,

you

would

then

record

positions

at

(0,-‐10),

(10,-‐5),

(20,

0),

and

(30,

5)

After

measuring

this

diagonal,

you

could

then

increment

the

azimuth

position

(often
accomplished

by

turning

the

subject’s

chair)

by

10

degrees.

Then

the

next

array

of
positions

would

be

defined

with

azimuth

starting

at

10

degrees,

with

all

other
parameters

remaining

the

same.

The sort

data

before

saving

checkbox

is
particularly

useful

when

recording

diagonal

position

arrays,

as

the

data

can

then

be
organized

easily

by

azimuth

and

elevation.

If

you

are

not

measuring

along

a

diagonal,

simply

enter

the

interval

angle

of

the
dimension

you

are

measuring

along

(azimuth

or

elevation),

and

enter

0

for

the
interval

of

the

other

dimension.

This

will

record

a

line

of

vertical

or

horizontal
postions.

## Multichannel

## Input

## Mode

Because

the

PortAudio

API

used

to

power

ScanIR

is

only

limited

by

the

number

of
channels

available

to

your

personal

audio

interface,

ScanIR

also

contains

a
Multichannel

Input

Mode

to

allow

measurement

simultaneously

on

a

large

number
of

input

channels.

While

the

uses

and

common

practices

for

a

measurement

system
of

this

type

are

not

yet

well

defined,

it

is

hoped

that

this

mode

will

allow

the

user

to
push

the

boundaries

of

smaller-‐scale

impulse

response

measurements

in

innovative
ways.

For

that

reason,

this

mode

is

defined

rather

flexibly,

allowing

the

user

greater
freedom

in

defining

his

or

her

own

uses

for

the

system.

Multichannel

input

mode

allows

the

user

to

measure

impulse

responses

on

the

time
scale

of

either

samples

or

seconds.

Thus,

if

a

user

wanted

to

generate

a

room
impulse

response

of

only

512

samples,

he

could

use

this

mode

rather

than

the
longer

impulse

responses

available

in

Mono

input

mode.

Conversely,

if

a

user

were
to

measure

HRIRs

in

a

reverberant

environment

and

wanted

to

keep

the

room
reflections

in

the

final

impulse

responses,

she

could

define

a

2-‐channel

session

in
this

mode

using

seconds

rather

than

samples.

This

mode

has

been

used

here

at

NYU’s

Music

and

Audio

Research

Laboratory

for
recording

dense

sound

radiation

measurements.

Using

a

prototype

array

of
microphones

spaced

closely

together,

this

mode

can

then

track

change

over

the

time
or

frequency

domain

between

measurements,

or

over

a

single

channel

as

the
microphone

array

is

rotated

around

a

sound

source

(using

the

Frequency

–

cascade
chl

visualization

option).

When

using

this

mode

to

measure

absolute

rather

than

relative

onsets

for

all
channels,

it

will

be

advisable

to

also

save

wavefiles

of

the

raw

recorded

data

as

well.
This

is

because

ScanIR

automatically

finds

the

first

peak

of

the

measured

impulse
responses

(for

all

measured

channels

at

once)

and

offsets

the

first

peak

by

100
samples

from

the

beginning

of

the

response

vector.

Thus,

relative

time

differences
between

channels

are

preserved

in

a

single

set

of

responses,

but

to

track

this

over

a
longer

period

of

time

the

raw

recorded

data

will

have

to

be

saved

and

analyzed.

As

the

uses

and

potential

of

this

mode

becomes

clearer,

future

versions

of

ScanIR
may

incorporate

new

organizational

features

or

optional

functionality

for
multichannel

impulse

response

recording

sessions.

# Final

# Things

Troubleshooting
If

you

have

troubleshooting

issues,

first

make

sure

that

your

audio

interface

is
connected

and

that

you’re

getting

a

good

clean

signal

in

and

out.

If

ScanIR

can’t

get

a
clean

signal,

your

impulse

response

will

be

all

noise

and

its

peak

detection

may
cause

an

indexing

error.

Watch

out

for

the

“Low

SNR”

warning.

So

far

this

has

only
happened

when

the

application

was

getting

no

sound

whatsoever,

but

do

be

mindful
of

it.

If

you

have

other

issues,

feel

free

to

let

me

know

at

bbb259@nyu.edu.

Obligatory

Thanks
Thanks

for

using

ScanIR.

I

hope

this

application

can

be

useful

to

you

and

your
research.

All

best

wishes,
Braxton

Boren

PhD

Student
New

York

University
Music

and

Audio

Research

Laboratory

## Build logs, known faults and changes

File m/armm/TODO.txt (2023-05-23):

I need to make a 3D model of the stepper attachment. 

We need a BoM for the ARMM, and instructions on how to build and run it. 

I wonder if the MATLAB structs work the same in Octave. 
	http://psychtoolbox.org/download toolbox should work in Octave
	There is also an arduino package. 

---
Pseudo:
* Center u-mic 1m away from source. 
* Input closest reflection path 
* 	Reflection path used for windowing 
* Inverse response (negate speaker effect)
* Single capsule equalization 
* A-format calibration 
* 	DFR method (horizontal only)
* B-format calibrationn 
*	Requires various angles, depending on order 
* Encode array 
*	Various methods to do this?
*		Based solely on geometry
*		Based on measurements
*		With additional constraints? DFR? (think MagLS approach)

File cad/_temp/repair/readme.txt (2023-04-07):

channel 5 in ada 8ch array repair

channel 2 in ada 16 ch array repair

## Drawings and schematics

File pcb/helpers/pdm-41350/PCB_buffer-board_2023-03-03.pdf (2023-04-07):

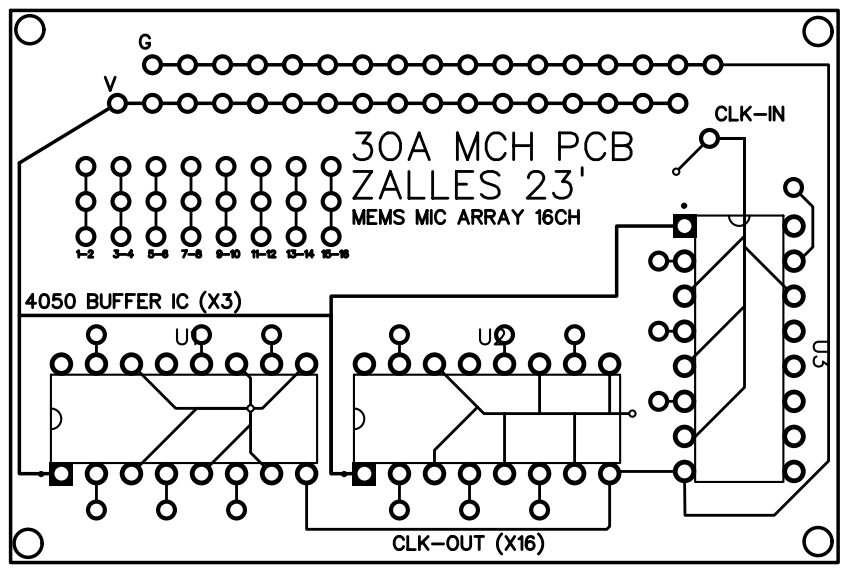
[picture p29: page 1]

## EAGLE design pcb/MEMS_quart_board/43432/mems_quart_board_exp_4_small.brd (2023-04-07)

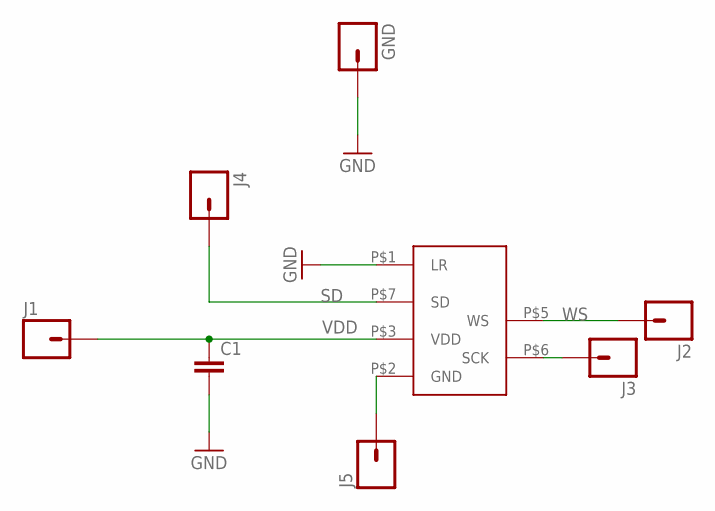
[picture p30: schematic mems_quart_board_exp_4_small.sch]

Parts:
C1: 0.1UF-16V(+-10%)(0402); 0402-CAP
GND: M01PTH_NO_SILK_YES_STOP; 1X01_NO_SILK
J1, J2, J3, J4, J5: M01NOSILK-KIT; 1X01NS-KIT
U$1: MEMS_ICS_43432

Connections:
GND: C1.2, GND.1, J5.1, U$1.P$1 (LR), U$1.P$2 (GND)
SCK: J3.1, U$1.P$6 (SCK)
SD: J4.1, U$1.P$7 (SD)
VDD: C1.1, J1.1, U$1.P$3 (VDD)
WS: J2.1, U$1.P$5 (WS)

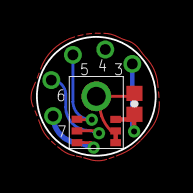
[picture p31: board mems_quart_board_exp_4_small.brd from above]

Board: 2 copper layers, 6.6 x 6.6 mm, 8 parts (0 on the bottom side), 5 nets.

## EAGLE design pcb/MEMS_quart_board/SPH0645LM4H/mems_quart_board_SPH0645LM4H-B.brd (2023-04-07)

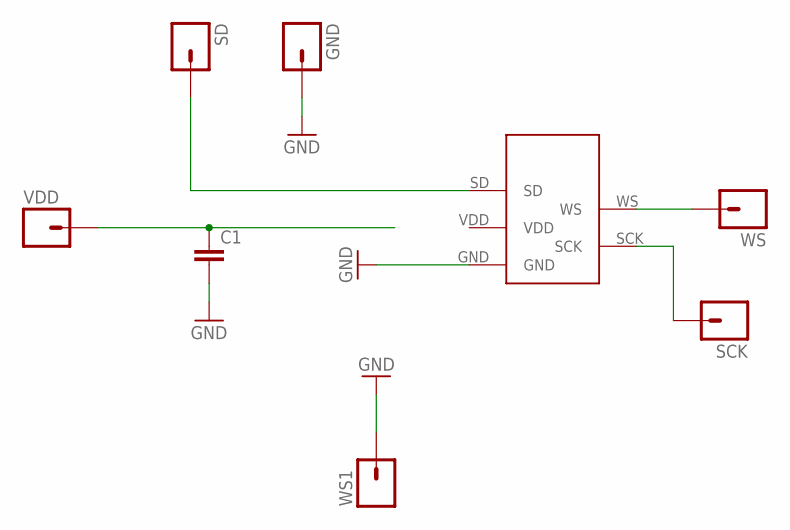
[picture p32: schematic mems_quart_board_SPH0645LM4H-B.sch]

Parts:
C1: 0.1UF-16V(+-10%)(0402); 0402-CAP
GND: M01PTH_NO_SILK_YES_STOP; 1X01_NO_SILK
SCK: M01NOSILK-KIT; 1X01NS-KIT
SD: M01NOSILK-KIT; 1X01NS-KIT
U$2: MEM_SPH0645LM4H-B; MEMS_SPH0645LM4H-B
VDD: M01NOSILK-KIT; 1X01NS-KIT
WS, WS1: M01NOSILK-KIT; 1X01NS-KIT

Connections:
GND: C1.2, GND.1, U$2.GND, WS1.1
unnamed: SCK.1, U$2.SCK
unnamed: SD.1, U$2.SD
unnamed: U$2.WS, WS.1
VDD: C1.1, U$2.VDD, VDD.1

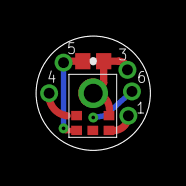
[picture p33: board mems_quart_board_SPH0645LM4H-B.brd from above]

Board: 2 copper layers, 6.3 x 6.3 mm, 8 parts (0 on the bottom side), 5 nets.

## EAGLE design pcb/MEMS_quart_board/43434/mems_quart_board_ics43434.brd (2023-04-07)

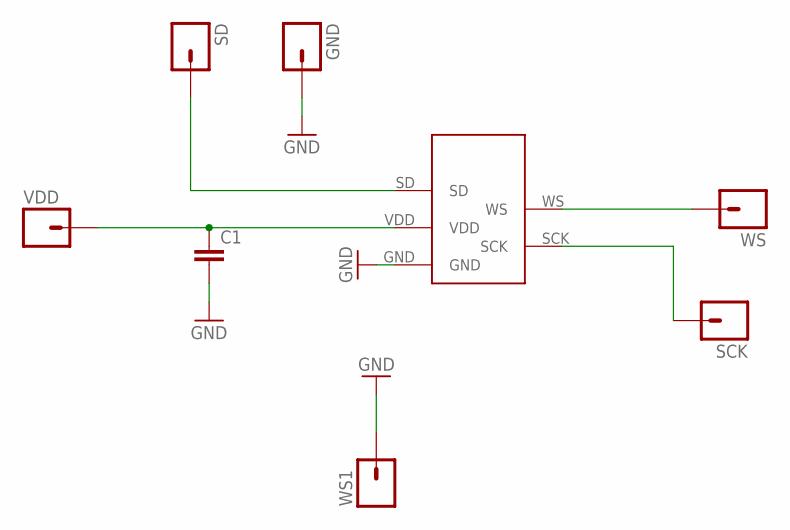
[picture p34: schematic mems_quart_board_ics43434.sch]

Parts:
C1: 0.1UF-16V(+-10%)(0402); 0402-CAP
GND: M01PTH_NO_SILK_YES_STOP; 1X01_NO_SILK
SCK: M01NOSILK-KIT; 1X01NS-KIT
SD: M01NOSILK-KIT; 1X01NS-KIT
U$1: MEM_ICS_43434; MEMS_ICS_43434
VDD: M01NOSILK-KIT; 1X01NS-KIT
WS, WS1: M01NOSILK-KIT; 1X01NS-KIT

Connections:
GND: C1.2, GND.1, U$1.GND, WS1.1
unnamed: SCK.1, U$1.SCK
unnamed: SD.1, U$1.SD
unnamed: U$1.WS, WS.1
VDD: C1.1, U$1.VDD, VDD.1

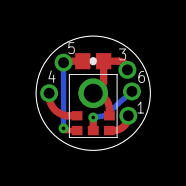
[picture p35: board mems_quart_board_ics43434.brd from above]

Board: 2 copper layers, 6.3 x 6.3 mm, 8 parts (0 on the bottom side), 5 nets.

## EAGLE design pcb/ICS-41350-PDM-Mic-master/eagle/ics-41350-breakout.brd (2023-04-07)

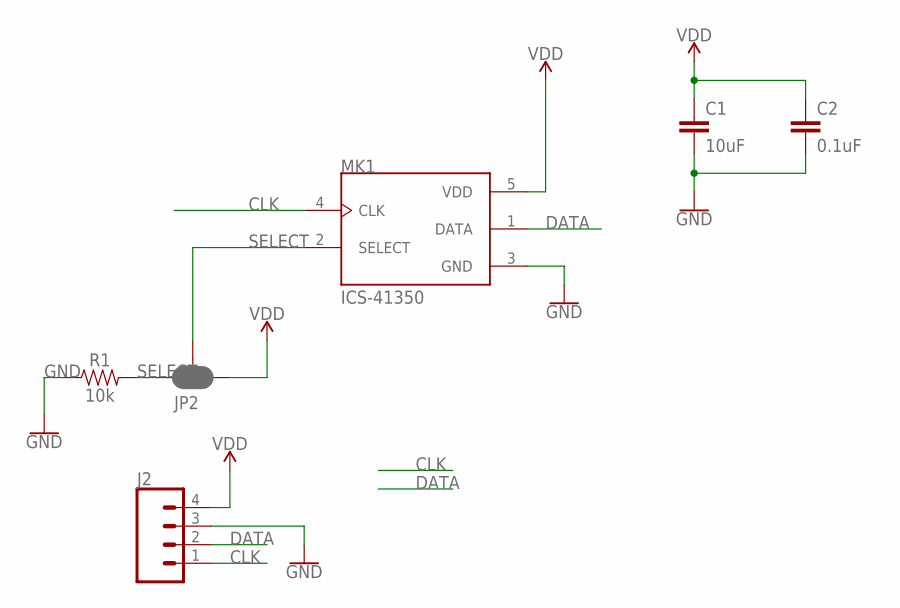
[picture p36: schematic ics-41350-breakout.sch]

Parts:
C1: 10uF; 0805
C2: 0.1uF; 0603
J2: CONN_041X04_NO_SILK; 1X04_NO_SILK
JP2: JUMPER-SMT_3_2-NC_PASTE_SILK; SMT-JUMPER_3_2-NC_PASTE_SILK
MK1: ICS-41350; MIC_ICS-41350
R1: 10k; 0603

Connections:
CLK: J2.1, MK1.4 (CLK)
DATA: J2.2, MK1.1 (DATA)
GND: C1.2, C2.2, J2.3, MK1.3 (GND), R1.1
SELECT: JP2.2, JP2.3, MK1.2 (SELECT), R1.2
VDD: C1.1, C2.1, J2.4, JP2.1, MK1.5 (VDD)

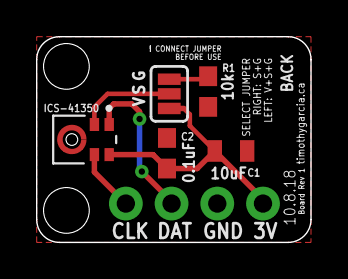
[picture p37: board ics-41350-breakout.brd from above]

Board: 2 copper layers, 15.2 x 11.4 mm, 6 parts (0 on the bottom side), 5 nets.

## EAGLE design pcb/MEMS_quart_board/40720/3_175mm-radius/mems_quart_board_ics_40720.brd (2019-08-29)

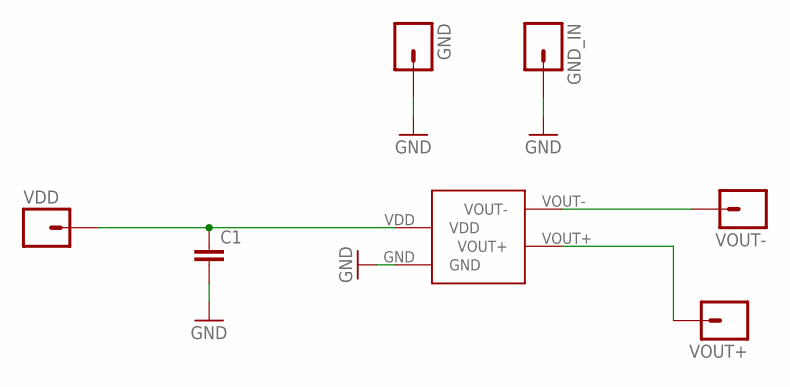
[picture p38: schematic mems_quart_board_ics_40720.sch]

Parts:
C1: 0.1UF-16V(+-10%)(0402); 0402-CAP
GND: M01PTH_NO_SILK_YES_STOP; 1X01_NO_SILK
GND_IN: M01NOSILK-KIT; 1X01NS-KIT
U$1: MEMS_ICS_40720
VDD: M01NOSILK-KIT; 1X01NS-KIT
VOUT+: M01NOSILK-KIT; 1X01NS-KIT
VOUT-: M01NOSILK-KIT; 1X01NS-KIT

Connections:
GND: C1.2, GND.1, GND_IN.1, U$1.GND
VDD: C1.1, U$1.VDD, VDD.1
VOUT+: U$1.VOUT+, VOUT+.1
VOUT-: U$1.VOUT-, VOUT-.1

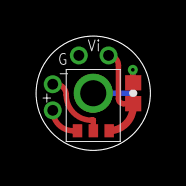
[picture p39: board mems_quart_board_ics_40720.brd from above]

Board: 2 copper layers, 6.3 x 6.3 mm, 7 parts (0 on the bottom side), 4 nets.

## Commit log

2019-04-29 update materials on readme
2019-05-01 more added to the materials section
2019-05-03 this is a message
    [3-sizes.obj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]
2019-05-03 case sensitive
2019-05-03 back to relative with string uper case
2019-05-03 more materials links etc.
2019-05-04 pushing readme modifications and gerzon filter. also stepper test. I want to write on the paper the methodology I used for getting my impulse response measurements. it would also be a goog idea to se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
2019-05-04 more instructions and links in the materials
2019-05-04 zipped gerber files, panelized
2019-05-05 the obj files looked all blurry stl seem to be better
    [3-sizes.obj, 3SizesFOA.stl]
2019-05-05 image to cad folder and a bit of info on the alligator mic clip;
2019-05-05 path change on cad image
2019-05-05 testing pages cad folder link?
2019-08-29 wiki recursion avoided
    [mems_quart_board_ics_40720.brd]
2020-10-08 links to papers via researchgate
    🎤
2020-10-29 jpg lower case
2023-04-07 I hope this works
    [1.75mm_mounted_pcb.stl, 1st_order_simple.stl, 1st_order_threaded_bot.stl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]
2023-04-19 sparta filters
    can be used with sparta convolver
2023-04-19 organizing and removing old things
    [1.75mm_mounted_pcb.stl, 1st_order_simple.stl, 1st_order_threaded_bot.stl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]
2023-04-19 upload filters
2023-05-23 various
    svgs for laser cut concept, some more STLs, scanIR
    [armm-attachment.stl, armm-attachments.stl, back.stl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]
2023-06-14 added templates for RPP
    [Drill_NPTH_Through.DRL, Drill_PTH_Through.DRL, Drill_PTH_Through_Via.DRL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]
2023-06-14 Revert "added templates for RPP" This reverts commit ec4b30c20bdef6908c59d66a3255f2a0dc4f4689.
    [Drill_NPTH_Through.DRL, Drill_PTH_Through.DRL, Drill_PTH_Through_Via.DRL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]

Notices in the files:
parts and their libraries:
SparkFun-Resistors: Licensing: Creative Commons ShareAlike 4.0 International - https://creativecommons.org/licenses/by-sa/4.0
